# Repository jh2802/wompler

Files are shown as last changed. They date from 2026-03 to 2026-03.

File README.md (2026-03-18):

# wompler
Wompler - 8 Voice Digital Sampler with MIDI Input for Eurorack

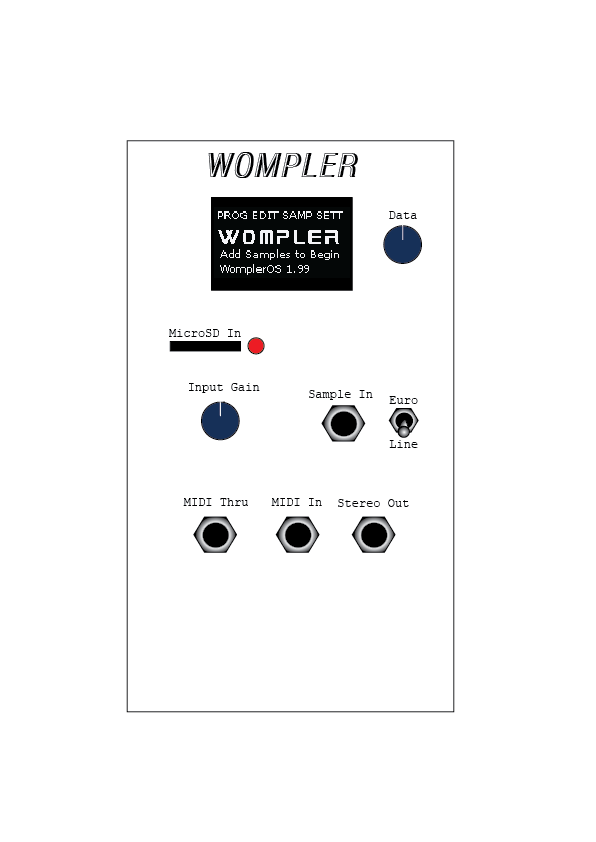
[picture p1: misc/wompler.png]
Wompler Image


ESP32 Based hardware, you can DIY this project for under $100, heck, you could make 5 for around that price.

Simplified software build instructions:
<br>
Tested with Arduino 1.8.19 using the espressif Arduino core for the ESP32 board version 2.0.11 
<br>
Place the folder "sources/streams_generator_i2sexperiment227" into your arduino sketches folder
<br>
Move the libraries from "/libraries" to your arduino libraries folder
<br>
find the line "#include "C:\Users\JJ Hardt\Documents\arduino-1.8.19\portable\sketchbook\libraries\audio-tools\src\AudioTools\MusicalNotes.h" and replace it with your correct install
<br>
Wompler manual:
<br>
https://docs.google.com/document/d/1GjeHvt_AO2QE2bgJas3L68PRGj3EGleQ7ScGcbaWzwo/edit?usp=sharing

Gerber files, PNP, and 3d printed panel found in "/hardware" folder as well as EasyEDA files

<a href="https://www.youtube.com/shorts/Yl5tXINzOkQ">Youtube audio demo:</a><br>
This demo shows an older version of wthe Wompler off

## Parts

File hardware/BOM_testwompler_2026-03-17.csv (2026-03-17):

ID | Name | Designator | Footprint | Quantity | Manufacturer Part | Manufacturer | Supplier | Supplier Part | Price
1 | 1uF | C1 | CAP-SMD_BD4.0-L4.3-W4.3-FD-LS5.1 | 1 | EEE1HA010NR | PANASONIC(松下) | LCSC | C401606 | 0.19
2 | 100nF | C2,C3,C4,C5,C6,C7,C16,C18,C21,C23,C25,C28,C29,C30,C31,C34,C35 | C0805 | 17 | CC0805KRX7R9BB104 | YAGEO(国巨) | LCSC | C49678 | 0.005
3 | 22uF | C8,C19,C22,C26,C32,C33 | C0805 | 6 | CL21A226MAQNNNE | SAMSUNG(三星) | LCSC | C45783 | 0.031
4 | 2.2nF | C10,C11 | C0805 | 2 | CL21C222JBFNNNE | SAMSUNG(三星) | LCSC | C28260 | 0.033
5 | 2.2uF | C12,C14 | C0402 | 2 | CL05A225MQ5NSNC | SAMSUNG(三星) | LCSC | C12530 | 0.003
6 | 10uF | C15,C17,C20,C24,C27 | C1206 | 5 | CL31A106KBHNNNE | SAMSUNG(三星) | LCSC | C13585 | 0.062
7 | 1N4148WS T4 | D1 | SOD-323_L1.8-W1.3-LS2.5-RD | 1 | 1N4148WS | CJ(江苏长电/长晶) | LCSC | C2128 | 0.009
8 | LED | D2 | LED-TH_LED-DP2-2LED-AMCC | 1 | 5600 | VccLite | Digi-Key | L20325-ND
9 | 100k | GAIN | BOURNS PTV09 GS | 1 | PTT111-3217A-B503 | Bourns | Mouser | 652-PTT111-3217A-B503
10 | AUDIO INPUT | J1 | WQP_PJ301M-12 | 1
11 | PROGRAM | J2 | HEADER MALE 2X3 P2.54 | 1 | PH2-06-UA | Adam Tech | Digi-Key | 2057-PH2-06-UA-ND
12 | AUDIO_OUT | J3 | PJ301_THONKICONN4 - FRONT PANEL W/ 6.05MM HOLE V2 | 1 |  | THONK | Thonk | PJ366ST
13 | PJ366ST | J4 | PJ301_THONKICONN4 - FRONT PANEL W/ 6.05MM HOLE V2 | 1 |  | THONK | Thonk | PJ366ST
14 | THRU | J5 | PJ301_THONKICONN4 - FRONT PANEL W/ 6.05MM HOLE V2 | 1 |  | THONK | Thonk | PJ366ST
15 | POWER | P1 | HDR-TH_16P-P2.54-V-M-R2-C8-S2.54 | 1 | 2.54-2*8P针 | BOOMELE(博穆精密) | LCSC | C68234 | 0.101
16 | 1kΩ | R1,R4,R11 | R0805 | 3 | 0805W8F1001T5E | UNI-ROYAL(厚声) | LCSC | C17513 | 0.003
17 | 10kΩ | R2,R18,R21,R22 | R0805 | 4 | 0805W8F1002T5E | UNI-ROYAL(厚声) | LCSC | C17414 | 0.003
18 | 2.2kΩ | R3 | R0805 | 1 | 0805W8F2201T5E | UNI-ROYAL(厚声) | LCSC | C17520 | 0.002
19 | 100R | R5,R6 | R0805 | 2 | 0805W8F1000T5E | UNI-ROYAL(厚声) | LCSC | C17408 | 0.002
20 | 47Ω | R7,R8,R9,R10 | R0805 | 4 | 0805W8F470JT5E | UNI-ROYAL(厚声) | LCSC | C17714 | 0.002
21 | 0Ω | R12,R35,R36 | R1206 | 3 | 1206W4F0000T5E | UNI-ROYAL(厚声) | LCSC | C17888 | 0.004
22 | 22Ω | R13,R14,R16 | R0805 | 3 | 0805W8F220JT5E | UNI-ROYAL(厚声) | LCSC | C17561 | 0.002
23 | 470Ω | R15,R17,R32 | R0805 | 3 | 0805W8F4700T5E | UNI-ROYAL(厚声) | LCSC | C17710 | 0.002
24 | 50Ω | R19,R27 | R0805 | 2 | ARG05FTC0500 | Viking(光颉) | LCSC | C2828866 | 0.009
25 | 270Ω | R20 | R0805 | 1 | 0805W8F2700T5E | UNI-ROYAL(厚声) | LCSC | C17590 | 0.003
26 | 100Ω | R23,R26 | R0603 | 2 | 0603WAF1000T5E | UNI-ROYAL(厚声) | LCSC | C22775 | 0.001
27 | 4.7kΩ | R24,R25,R28,R29,R31 | R0805 | 5 | 0805W8F4701T5E | UNI-ROYAL(厚声) | LCSC | C17673 | 0.002
28 | 220Ω | R30 | R0402 | 1 | 0402WGF2200TCE | UNI-ROYAL(厚声) | LCSC | C25091 | 0.001
29 | 10Ω | R33 | R1206 | 1 | 1206W4F100JT5E | UNI-ROYAL(厚声) | LCSC | C17903 | 0.004
30 | 33Ω | R34 | R0603 | 1 | 0603WAJ0330T5E | UNI-ROYAL(厚声) | LCSC | C25232 | 0.001
31 | 0Ω | R40,R41 | R2010 | 2 | WR20X000PTL | Walsin(华新科) | LCSC | C168598 | 0.012
32 | SW-T3-1A-A-A3-S1 | SW1 | SW-T3-1A-A-A3-S1 | 1 | SW-T3-1A-A-A3-S1 | Adam Tech | Digi-Key | 2057-SW-T3-1A-A-A3-S1-ND
33 | EC11E156T402 | SW2 | SW-TH_EC11E156T402 | 1 | EC11E156T402 | ALPSALPINE(阿尔卑斯阿尔派) | LCSC | C2687292 | 2.22
34 | TL072CDT | U1 | SOIC-8_L5.0-W4.0-P1.27-LS6.0-BL | 1 | TL072CDT | ST(意法半导体) | LCSC | C6961 | 0.186
35 | PCM1808PWR | U2 | TSSOP-14_L5.0-W4.4-P0.65-LS6.4-BL | 1 | PCM1808PWR | TI(德州仪器) | LCSC | C55513 | 0.645
36 | ESP32-WROOM-32E-H4 | U3 | WIFI-SMD_ESP32-WROOM-32E | 1 | ESP32-WROOM-32E-H4 | ESPRESSIF(乐鑫) | LCSC | C3013935 | 4.031
37 | PCM5102APWR | U4 | TSSOP-20_L6.5-W4.4-P0.65-LS6.4-BL | 1 | PCM5102APWR | TI(德州仪器) | LCSC | C107671 | 1.43
38 | AMS1117-3.3 | U6,U7,U8,U12 | SOT-223-3_L6.5-W3.4-P2.30-LS7.0-BR | 4 | AMS1117-3.3 | AMS | LCSC | C6186 | 0.226
39 | SD CARD READER PJS008U-3000-0 | U10 | PJS008U-3000-0 | 1 | SF72S006VBAR2500 |  | Digi-Key | 670-2799-1-ND
40 | DISPLAY | U11 | 04X1-HEADER-MALE | 1 |  |  |  | undefined
41 | 6N138 | U13 | 6N138 | 1 | 6N138 | Isocom Components | LCSC | C255743 | 0.378
42 | 74LVC1G07GV,125 | U14 | SOT-753_L3.1-W1.7-P0.95-LS3.0-BR | 1 | 74LVC1G07GV,125 | Nexperia(安世) | LCSC | C12511 | 0.261
43 | TL074CDR | U9 | SOIC-14_L8.7-W3.9-P1.27-LS6.0-BL | 1 | TL074CDR | TI(德州仪器) | LCSC | C12594 | 0.199

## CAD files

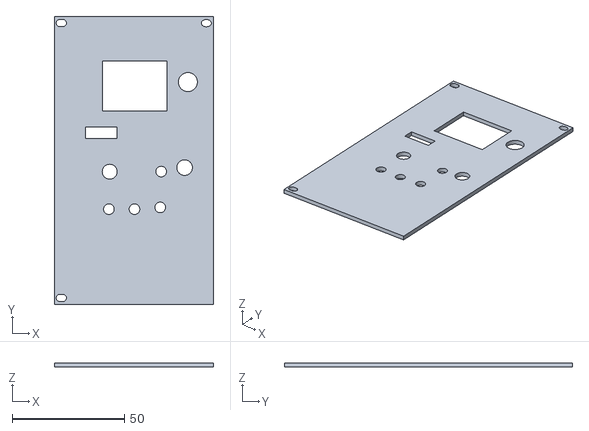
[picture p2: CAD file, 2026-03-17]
hardware/womplerrev2.stl
70.8 x 128.4 x 2.00

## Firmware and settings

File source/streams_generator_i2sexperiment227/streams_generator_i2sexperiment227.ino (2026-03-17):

/**
 * @file streams-generator-i2s.ino
 * @author Phil Schatzmann
 * @brief see https://github.com/pschatzmann/arduino-audio-tools/blob/main/examples/examples-stream/streams-generator-i2s/README.md 
 * @copyright GPLv3
 */

#include "AiEsp32RotaryEncoder.h"
#include <stack>
#include "FS.h"
#include "SD.h"
#include "SPI.h"
#include <Update.h>


//FOR WOMPLER XM TESTS
#define RX2 14
//end wompler xm test

bool preview=true;
#define SMPL 1936552044
const int16_t pb_power [24]  = {-48,-46,-44,-42,-39,-36,-32,-28,-24,-19,-13,-7,8,17,27,38,50,65,80,98,118,140,165,194};
// 'wompler1', 123x22px
const uint8_t oscmode_to_partialmode[6]={0,1,1,2,3,4};
const unsigned char epd_bitmap_wompler1 []  = {
	0x00, 0x00, 0x00, 0x00, 0x00, 0x00, 0x00, 0x00, 0x00, 0x00, 0x00, 0x00, 0x00, 0x00, 0x00, 0x00, 
	0x00, 0x00, 0x00, 0x00, 0x00, 0x00, 0x00, 0x00, 0x00, 0x00, 0x00, 0x00, 0x00, 0x00, 0x00, 0x00, 
	0x00, 0x00, 0x00, 0x00, 0x00, 0x00, 0x00, 0x00, 0x00, 0x00, 0x00, 0x00, 0x00, 0x00, 0x00, 0x00, 
	0x00, 0x00, 0x00, 0x00, 0x00, 0x00, 0x00, 0x00, 0x00, 0x00, 0x00, 0x00, 0x00, 0x00, 0x00, 0x00, 
	0x0c, 0x00, 0x60, 0x7f, 0xf0, 0x20, 0x01, 0x03, 0xff, 0x83, 0x80, 0x07, 0xfe, 0x0f, 0xfe, 0x00, 
	0x0c, 0x00, 0x60, 0x7f, 0xf0, 0x30, 0x03, 0x03, 0xff, 0x83, 0x80, 0x07, 0xfe, 0x0f, 0xfe, 0x00, 
	0x0e, 0x00, 0x60, 0xe0, 0x38, 0x38, 0x07, 0x00, 0x01, 0x83, 0x80, 0x00, 0x00, 0x00, 0x06, 0x00, 
	0x0e, 0x10, 0xe0, 0xe0, 0x38, 0x3c, 0x0f, 0x00, 0x01, 0x83, 0x80, 0x00, 0x00, 0x00, 0x06, 0x00, 
	0x0e, 0x38, 0xe0, 0xe0, 0x38, 0x3e, 0x1f, 0x00, 0x01, 0x83, 0x80, 0x00, 0x00, 0x00, 0x06, 0x00, 
	0x0e, 0x7c, 0xe0, 0xe0, 0x38, 0x3f, 0x1f, 0x80, 0x01, 0x83, 0x80, 0x00, 0x00, 0x00, 0x06, 0x00, 
	0x0e, 0xfe, 0xe0, 0xe0, 0x38, 0x3b, 0xbb, 0x80, 0x03, 0x83, 0x80, 0x07, 0xfc, 0x0f, 0xfe, 0x00, 
	0x0f, 0xef, 0xe0, 0xe0, 0x38, 0x3b, 0xf3, 0x83, 0xff, 0x83, 0x80, 0x07, 0xfc, 0x0f, 0xfe, 0x00, 
	0x0f, 0xc7, 0xe0, 0xe0, 0x38, 0x39, 0xe3, 0x83, 0xff, 0x03, 0x80, 0x07, 0x00, 0x0e, 0x70, 0x00, 
	0x0f, 0x83, 0xe0, 0xe0, 0x38, 0x30, 0xc3, 0x83, 0x80, 0x03, 0x80, 0x07, 0x00, 0x0e, 0x30, 0x00, 
	0x0f, 0x01, 0xc0, 0xe0, 0x38, 0x30, 0x03, 0x83, 0x80, 0x03, 0x80, 0x07, 0x00, 0x0e, 0x38, 0x00, 
	0x06, 0x00, 0xc0, 0xf0, 0x78, 0x70, 0x03, 0x83, 0x80, 0x03, 0x80, 0x07, 0x00, 0x0e, 0x1c, 0x00, 
	0x04, 0x00, 0x40, 0x7f, 0xf0, 0x70, 0x03, 0x83, 0x80, 0x03, 0xff, 0x87, 0xfe, 0x0e, 0x1c, 0x00, 
	0x00, 0x00, 0x00, 0x3f, 0xe0, 0x70, 0x03, 0x83, 0x80, 0x03, 0xff, 0x87, 0xfe, 0x0e, 0x0e, 0x00, 
	0x00, 0x00, 0x00, 0x00, 0x00, 0x00, 0x00, 0x00, 0x00, 0x00, 0x00, 0x00, 0x00, 0x00, 0x00, 0x00, 
	0x00, 0x00, 0x00, 0x00, 0x00, 0x00, 0x00, 0x00, 0x00, 0x00, 0x00, 0x00, 0x00, 0x00, 0x00, 0x00, 
	0x00, 0x00, 0x00, 0x00, 0x00, 0x00, 0x00, 0x00, 0x00, 0x00, 0x00, 0x00, 0x00, 0x00, 0x00, 0x00, 
	0x00, 0x00, 0x00, 0x00, 0x00, 0x00, 0x00, 0x00, 0x00, 0x00, 0x00, 0x00, 0x00, 0x00, 0x00, 0x00
};
// 'wompler2', 123x22px
const unsigned char epd_bitmap_wompler2 []  = {
	0x00, 0x00, 0x00, 0x00, 0x00, 0x00, 0x00, 0x00, 0x00, 0x00, 0x00, 0x00, 0x00, 0x00, 0x00, 0x00, 
	0x00, 0x00, 0x00, 0x00, 0x00, 0x00, 0x00, 0x00, 0x00, 0x00, 0x00, 0x00, 0x00, 0x00, 0x00, 0x00, 
	0x3f, 0x01, 0xf9, 0xff, 0xfc, 0xf8, 0x07, 0xcf, 0xff, 0xef, 0xe0, 0x1f, 0xff, 0xbf, 0xff, 0x80, 
	0x21, 0x01, 0x09, 0x00, 0x04, 0x8c, 0x0c, 0x48, 0x00, 0x28, 0x20, 0x10, 0x00, 0xa0, 0x00, 0x80, 
	0x2d, 0x81, 0x6b, 0x7f, 0xf6, 0xa6, 0x19, 0x4b, 0xff, 0xab, 0xa0, 0x17, 0xfe, 0xaf, 0xfe, 0x80, 
	0x2c, 0xff, 0x6a, 0x7f, 0xf2, 0xb3, 0x33, 0x4b, 0xff, 0xab, 0xa0, 0x17, 0xfe, 0xaf, 0xfe, 0x80, 
	0x2e, 0xc6, 0x6a, 0xe0, 0x3a, 0xb9, 0xe7, 0x48, 0x01, 0xab, 0xa0, 0x10, 0x00, 0xa0, 0x06, 0x80, 
	0x2e, 0x92, 0xea, 0xef, 0xba, 0xbc, 0xcf, 0x6f, 0xfd, 0xab, 0xa0, 0x1f, 0xff, 0xbf, 0xf6, 0x80, 
	0x2e, 0x38, 0xea, 0xe8, 0xba, 0xbe, 0x5f, 0x20, 0x0d, 0xab, 0xa0, 0x1f, 0xff, 0x3f, 0xf6, 0x80, 
	0x2e, 0x7c, 0xea, 0xea, 0xba, 0xbf, 0x1f, 0xaf, 0xf9, 0xab, 0xa0, 0x10, 0x01, 0x20, 0x06, 0x80, 
	0x2e, 0xfe, 0xea, 0xea, 0xba, 0xbb, 0xbb, 0xa8, 0x03, 0xab, 0xa0, 0x17, 0xfd, 0x2f, 0xfe, 0x80, 
	0x2f, 0xef, 0xea, 0xea, 0xba, 0xbb, 0xf3, 0xab, 0xff, 0xab, 0xa0, 0x17, 0xfd, 0x2f, 0xfe, 0x80, 
	0x2f, 0xc7, 0xea, 0xe8, 0xba, 0xb9, 0xe3, 0xab, 0xff, 0x2b, 0xa0, 0x17, 0x01, 0x2e, 0x70, 0x80, 
	0x2f, 0x93, 0xea, 0xed, 0xbb, 0xb0, 0xcb, 0xab, 0x80, 0x6b, 0xa0, 0x17, 0x7f, 0x2e, 0x33, 0x80, 
	0x2f, 0x39, 0xca, 0xe7, 0x3b, 0x36, 0x1b, 0xab, 0xbf, 0xcb, 0xbf, 0xf7, 0x7f, 0xae, 0xb9, 0x00, 
	0x26, 0x6c, 0xda, 0xf0, 0x7b, 0x77, 0xfb, 0xab, 0xa0, 0x0b, 0x80, 0x37, 0x00, 0xae, 0x9d, 0x80, 
	0x34, 0xc6, 0x52, 0x7f, 0xf3, 0x74, 0x0b, 0xab, 0xa0, 0x0b, 0xff, 0xb7, 0xfe, 0xae, 0xdc, 0x80, 
	0x11, 0x83, 0x13, 0x3f, 0xe7, 0x74, 0x0b, 0xab, 0xa0, 0x0b, 0xff, 0xb7, 0xfe, 0xae, 0xce, 0x80, 
	0x1f, 0x01, 0xf1, 0x80, 0x0d, 0x04, 0x08, 0x28, 0x20, 0x08, 0x00, 0x30, 0x00, 0xa0, 0xe0, 0x80, 
	0x00, 0x00, 0x00, 0xff, 0xf9, 0xfc, 0x0f, 0xef, 0xe0, 0x0f, 0xff, 0xff, 0xff, 0xbf, 0xbf, 0x80, 
	0x00, 0x00, 0x00, 0x00, 0x00, 0x00, 0x00, 0x00, 0x00, 0x00, 0x00, 0x00, 0x00, 0x00, 0x00, 0x00, 
	0x00, 0x00, 0x00, 0x00, 0x00, 0x00, 0x00, 0x00, 0x00, 0x00, 0x00, 0x00, 0x00, 0x00, 0x00, 0x00
};
// 'wompler3', 123x22px
const unsigned char epd_bitmap_wompler3 []  = {
	0xff, 0xc7, 0xff, 0xff, 0xff, 0xfe, 0x1f, 0xff, 0xff, 0xff, 0xf8, 0x7f, 0xff, 0xff, 0xff, 0xe0, 
	0x80, 0x44, 0x00, 0x00, 0x00, 0x03, 0x30, 0x00, 0x00, 0x00, 0x08, 0x40, 0x00, 0x00, 0x00, 0x20, 
	0xbf, 0x65, 0xf9, 0xff, 0xfc, 0xf9, 0xe7, 0xcf, 0xff, 0xef, 0xe8, 0x5f, 0xff, 0xbf, 0xff, 0xa0, 
	0xa1, 0x3d, 0x09, 0x00, 0x04, 0x8c, 0xcc, 0x48, 0x00, 0x28, 0x28, 0x50, 0x00, 0xa0, 0x00, 0xa0, 
	0xad, 0x81, 0x6b, 0x7f, 0xf6, 0xa6, 0x19, 0x4b, 0xff, 0xab, 0xa8, 0x57, 0xfe, 0xaf, 0xfe, 0xa0, 
	0xac, 0xff, 0x6a, 0x7f, 0xf2, 0xb3, 0x33, 0x4b, 0xff, 0xab, 0xa8, 0x57, 0xfe, 0xaf, 0xfe, 0xa0, 
	0xae, 0xc6, 0x6a, 0xe0, 0x3a, 0xb9, 0xe7, 0x48, 0x01, 0xab, 0xa8, 0x50, 0x00, 0xa0, 0x06, 0xa0, 
	0xae, 0x92, 0xea, 0xef, 0xba, 0xbc, 0xcf, 0x6f, 0xfd, 0xab, 0xa8, 0x5f, 0xff, 0xbf, 0xf6, 0xa0, 
	0xae, 0x38, 0xea, 0xe8, 0xba, 0xbe, 0x5f, 0x20, 0x0d, 0xab, 0xa8, 0x5f, 0xff, 0x3f, 0xf6, 0xa0, 
	0xae, 0x7c, 0xea, 0xea, 0xba, 0xbf, 0x1f, 0xaf, 0xf9, 0xab, 0xa8, 0x50, 0x01, 0x20, 0x06, 0xa0, 
	0xae, 0xfe, 0xea, 0xea, 0xba, 0xbb, 0xbb, 0xa8, 0x03, 0xab, 0xa8, 0x57, 0xfd, 0x2f, 0xfe, 0xa0, 
	0xaf, 0xef, 0xea, 0xea, 0xba, 0xbb, 0xf3, 0xab, 0xff, 0xab, 0xa8, 0x57, 0xfd, 0x2f, 0xfe, 0xa0, 
	0xaf, 0xc7, 0xea, 0xe8, 0xba, 0xb9, 0xe3, 0xab, 0xff, 0x2b, 0xaf, 0xd7, 0x01, 0x2e, 0x70, 0xa0, 
	0xaf, 0x93, 0xea, 0xed, 0xbb, 0xb0, 0xcb, 0xab, 0x80, 0x6b, 0xa0, 0x17, 0x7f, 0x2e, 0x33, 0xa0, 
	0xaf, 0x39, 0xca, 0xe7, 0x3b, 0x36, 0x1b, 0xab, 0xbf, 0xcb, 0xbf, 0xf7, 0x7f, 0xae, 0xb9, 0x20, 
	0xa6, 0x6c, 0xda, 0xf0, 0x7b, 0x77, 0xfb, 0xab, 0xa0, 0x0b, 0x80, 0x37, 0x00, 0xae, 0x9d, 0xa0, 
	0xb4, 0xc6, 0x52, 0x7f, 0xf3, 0x74, 0x0b, 0xab, 0xaf, 0xeb, 0xff, 0xb7, 0xfe, 0xae, 0xdc, 0xa0, 
	0x91, 0x93, 0x13, 0x3f, 0xe7, 0x75, 0xeb, 0xab, 0xa8, 0x2b, 0xff, 0xb7, 0xfe, 0xae, 0xce, 0xa0, 
	0xdf, 0x39, 0xf1, 0x80, 0x0d, 0x05, 0x28, 0x28, 0x28, 0x28, 0x00, 0x30, 0x00, 0xa0, 0xe0, 0xa0, 
	0x40, 0x6c, 0x04, 0xff, 0xf9, 0xfd, 0x2f, 0xef, 0xe8, 0x2f, 0xff, 0xff, 0xff, 0xbf, 0xbf, 0xa0, 
	0x7f, 0xc7, 0xfe, 0x00, 0x00, 0x01, 0x20, 0x00, 0x08, 0x20, 0x00, 0x00, 0x00, 0x00, 0x00, 0x20, 
	0x00, 0x00, 0x03, 0xff, 0xff, 0xff, 0x3f, 0xff, 0xf8, 0x3f, 0xff, 0xff, 0xff, 0xff, 0xff, 0xe0
};

// Array of all bitmaps for convenience. (Total bytes used to store images in  = 1104)





#define VOICE_QT 8
//#define LFO_QT 2 * VOICE QT
#define RIFF 1380533830
#define WAVE 1463899717
#define FACT 1717658484
#define DATA_ID 1684108385
const char *my_file;
#define FMTT 1718449184

#define FIRMWARE_VERSION "Build 31026"
//int long_press;
uint8_t voice2pitch[VOICE_QT];
bool enable_click=true;
int update_prog=0;
uint8_t pb_range=0;
bool dual_init=false;
String filename;
uint8_t edit_dest;
bool is_replace=false;
#include "do1.h"
bool sustain=false;
uint8_t sample_length=172;
uint8_t sample_threshold=0;
uint8_t sample_pos=0;
int samp_level_average_cache=0;
int8_t samp_level_average=0;
bool sd_init=false;
float boost_factor=1.0;
uint8_t dir_pos=0;
uint8_t edit_wavesample_2=0;
int edit_wavesample_buffer=0;
bool keystate[128];
const char *test_dir = "/";
const char *prev_dir = "/";
const char *file_save_path ="/test";
const char *test_dir_root = "/";
char sample_name[9]="USERSAMP";
int16_t next_dir_pos=0;
int16_t prev_dir_pos=0;
uint8_t fm_type=0;
File root;
File dir_file;
File dir_file_cache;
File prev_dir_file[6];
int8_t file_layer=0;
extern bool getKeystate(byte key){
    return keystate[key];
}

int8_t old_sample_pos;


#define ROTARY_ENCODER_A_PIN 25
#define ROTARY_ENCODER_B_PIN 27
#define ROTARY_ENCODER_BUTTON_PIN 4
#define ROTARY_ENCODER_STEPS 4
#define ROTARY_ENCODER_VCC_PIN -1 
#define SAMP_LEN 512

#define STEAL_FADE_TIME 4096
#define LOWPASS 0
#define HIGHPASS 1

#define WSB_HEADER 826430295
#define WSB2_HEADER 843207511
#define WSB3_HEADER 859984727
int8_t wavesample_combine=0;
bool sample_ready=false;
bool ld_default=false;
bool oscy=false;
char key2voice[128];
int8_t zoom=0;
bool queue_test=false;
uint8_t midi_channel=1;
uint8_t gp_reg8b=0;
bool nprog=0;
uint8_t gp_reg8a=0; //used for splashscreen animation and rectify mode
int8_t user_wavesamples = 0;
void writeFile(fs::FS &fs, const char * path, const char * message){
    Serial.printf("Writing file: %s\n", path);

    File file = fs.open(path, FILE_WRITE);
    if(!file){
        Serial.println("Failed to open file for writing");
        return;
    }
    if(file.print(message)){
        Serial.println("File written");
    } else {
        Serial.println("Write failed");
    }
    file.close();
}


void appendFile(fs::FS &fs, const char * path, const char * message){
    Serial.printf("Appending to file: %s\n", path);

    File file = fs.open(path, FILE_APPEND);
    if(!file){
        Serial.println("Failed to open file for appending");
        return;
    }
    if(file.print(message)){
        Serial.println("Message appended");
    } else {
        Serial.println("Append failed");
    }
    file.close();
}
SPIClass sd_spi(HSPI);

#define SD_CS 5
#define SD_MOSI 23
#define SD_MISO 19
#define SD_SCLK 18


#define FM_SAMPLE 0
#define FM_BANK 1
#define FM_DIRWAV 2
#define FM_DIRBNK 3
//char voice2key[max_voices]={255,255,255,255,255,255}; 
//byte queuePitch[max_voices]={0,0,0,0,0,0};
//byte queueVelo[max_voices]={0,0,0,0,0,0};
char voice2key[VOICE_QT]={255,255,255,255,255,255,255,255}; 
byte queuePitch[VOICE_QT]={0,0,0,0,0,0};
byte queueVelo[VOICE_QT]={0,0,0,0,0,0};
#define WAVESAMPLE_AMOUNT 100
#define PROGRAM_AMOUNT 64
#define VOICE_HF VOICE_QT>>1
bool voices_init=false;
byte last_velo=0;
#define DEFAULT 0
#define PER_WAVESAMPLE 1
#define POLY2 2
byte poly_mode=DEFAULT;
#define ROUND_ROBIN 2
#include <MIDI.h>
#include "logtable.h"
//#include "sqlw.h"

AiEsp32RotaryEncoder rotaryEncoder = AiEsp32RotaryEncoder(ROTARY_ENCODER_A_PIN, ROTARY_ENCODER_B_PIN, ROTARY_ENCODER_BUTTON_PIN, ROTARY_ENCODER_VCC_PIN, ROTARY_ENCODER_STEPS);

extern void setQueuedNote(byte voice,byte pitch,byte velo) {
queuePitch[voice]=pitch;
queueVelo[voice]=velo;

}



#include <Wire.h>
#include <Adafruit_GFX.h>
#include <Adafruit_SSD1306.h>


#define LOGO16_GLCD_HEIGHT 16
#define LOGO16_GLCD_WIDTH  16
#define SCREEN_WIDTH 128 // OLED display width, in pixels
#define SCREEN_HEIGHT 64 // OLED display height, in pixels
#define OLED_RESET     -1 // Reset pin # (or -1 if sharing Arduino reset pin)
#define SCREEN_ADDRESS 0x3C ///< See datasheet for Address; 0x3D for 128x64, 0x3C for 128x32
Adafruit_SSD1306 display(SCREEN_WIDTH, SCREEN_HEIGHT, &Wire, OLED_RESET);
#include "AudioTools.h"
#include "C:\Users\JJ Hardt\Documents\arduino-1.8.19\portable\sketchbook\libraries\audio-tools\src\AudioTools\MusicalNotes.h"
int8_t samp_level_buffer[128]={};
bool sampling_level=false;
//ChannelConverter<int32_t> converter(16,32);
AudioInfo from(30000,2,24);
AudioInfo to(30000,2,16);
MemoryOutput samp_mem_out{(uint8_t*)samp_memory,88064};
MemoryOutput samp_level{(uint8_t*)samp_level_buffer,128};
ConverterFillLeftAndRight<int16_t> sampfix(LeftIsEmpty,2);
volatile int16_t lfo[VOICE_QT];
volatile uint8_t random_counter[VOICE_QT];
volatile int16_t saw[VOICE_QT];
volatile int16_t tri;
//int totalInterruptCounter;

hw_timer_t * timer = NULL;
portMUX_TYPE timerMux = portMUX_INITIALIZER_UNLOCKED;
MIDI_CREATE_INSTANCE(HardwareSerial, Serial2, DIN_MIDI);
const uint16_t sample_rate=30000;
const uint8_t channels = 2;
char mode=0;    
int men[VOICE_QT];

char voice2ws[VOICE_QT];             
AudioInfo sampy(sample_rate,1,8);
byte program=0;

//AUDIO PROCESS FILTER CONSTANTS
#define FILTER_D_LP 0
#define FILTER_D_HP 1
#define FILTER_D_BP 2
#define FILTER_D_BR 3
#define FILTER_D_PKG 4

//DISPLAY CONTEXT CONSTANTS

//MAIN MENU
#define PROG 0
#define SAMPLE 2
#define EDIT 1
#define SETTINGS 3

// EDIT MENU
#define EDIT_SAMP 4
#define AMP_MENU 5
#define MOD_MENU 6
#define MORE 7

#define LOOP_MENU 8
#define FILTER 9
#define KEYSET 10
#define MORE_SAMPEDIT 11
//AMP EG MENU
#define AMP_EG_ATK 12
#define AMP_EG_DEC 13
#define AMP_EG_SUS 14
#define AMP_EG_REL 15

//keyset menu
#define KEYSET_TOPKEY 216
#define KEYSET_CTUNE 217
#define KEYSET_KEYT 218
#define KEYSET_FTUNE 219
#define KEYSET_PORTATIME 220
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
void loop() {
  //Serial.println(is_replace);
  if (sampling==true){

  if (samp_num<sample_length ){
  // sample_copy.copy();
   sample_copy.copy();
   samp_num++;
   Serial.println(samp_num);
   } 

   if (samp_num==sample_length){
      displaycontext=SAMPLE_EDITOR;
      sampling=false;
      uint8_t user_wavesamples_cache=user_wavesamples;
      if (is_replace==true){user_wavesamples=edit_wavesample;}
       wavesample_start[user_wavesamples]=(sample_pos*512);
      wavesample_loopst[user_wavesamples]=wavesample_start[user_wavesamples];
      wavesample_end[user_wavesamples]=wavesample_start[user_wavesamples]+(sample_length*512)-1;
       wavesample_loopen[user_wavesamples]=wavesample_end[user_wavesamples];
       edit_wavesample=user_wavesamples;
       if (is_replace==false){ user_wavesamples++;} else{
user_wavesamples=user_wavesamples_cache;
       }
       if (nprog==true){
         program=user_programs;
         program++;
         program_init_ws[program]=edit_wavesample;
          user_programs++;
          prev_osc_mode=osc_mode;
          osc_mode=0;
  poly_mode=0;
       }
       menuoffset=ZOOM-4;
       hovermode=true;
       hovercontext=ZOOM;
       rotaryEncoder.setEncoderValue(4);
       rotaryEncoder.setBoundaries(0,7, true); 
      refreshDisplay();
     
      sample_pos+=sample_length;
     
      
      copier.begin(out,voice_mixer);
   }
   
   /*else {
     if (ld_default==false){
loadBank(SD, "/default.wsb");
refreshDisplay();
  copier.begin(out,voice_mixer);
ld_default=true;

     }
     sampling=false;
   
   }*/
  
  } else {
  
  if (sampling_level==false){
    copier.copy();}
    
if (sampling_level==true){
  //copier1.copy();
level_copy.copy();

samp_level_average=samp_level_average_cache;
samp_level_average_cache=0;
for(int i=0;i<128;i++){

samp_level_average_cache+=abs(samp_level_buffer[i]);

}
samp_level_average_cache=samp_level_average_cache/128;
samp_level_average=((samp_level_average_cache + samp_level_average)/2);
 samp_level.reset();
  if (sample_ready==false){

  refreshDisplay();
  }

if ((sample_ready==true) && (samp_level_average>=sample_threshold)){
   // copier.begin(out,converter);
    sampling=true;
  refreshDisplay();
      samp_mem_out.setPosX(((int)(sample_pos)*512));
      samp_mem_out.begin();
     
      //samp_level.begin();
      //bitcrush.begin();
      //final_samp.begin(2,1);
      sample_copy.begin();
     // level_copy.end();
     samp_num=0;
      sampling_level=false;
     sample_ready=false;
    // sampling=true;
      auto config_in = adc.defaultConfig(RX_MODE);
config_in.buffer_count=4;
  config_in.buffer_size=512;

     

}


 

}
   


//recording a sample



  /*
  Serial.println(String(esp_get_free_heap_size()));
  out.end();
 
 int sample_timer=0;

 while (sample_timer<512){
   
   if (adc.available()==512){

 size_t len = adc.readBytes(samp_buff, 512); 
  // move center to 0 and scale the values
  scaler.convert(samp_buff, len);

  int16_t *sample = (int16_t*) samp_buff; 
 
  for (int j=0; j<len/2; j++){
    int xj=j+(sample_timer*256);
    samp_memory[xj]=(*sample++);
  ;
  }
sample_timer++;
}
}
/*
 auto config = out.defaultConfig(TX_MODE);
  config.buffer_count=4;
  config.buffer_size=64;
  config.sample_rate = sample_rate; 
  config.channels = channels;
  config.port_no=1;
  config.bits_per_sample = 16;
out.begin(config);

 for (int i;i<65536;i++){
  Serial.println( samp_memory[i] ); };

   size_t len = adc.readBytes(samp_buff, 256); 
  // move center to 0 and scale the values
  scaler.convert(samp_buff, len);

  int16_t *sample = (int16_t*) samp_buff; 
  int size = len;// / 4;
  for (int j=0; j<size; j++){
    samp_memory[j+(m*4096)]=(*sample++);
  }
Wire.beginTransmission(0x55);
  Wire.write(200);
Wire.endTransmission(); 
  m++; 
//Write message to the slave

  // Clear the buffer.
 
 
  
 
 

 */

 
if (laststate==HIGH && digitalRead(13)==LOW){

onButtonClick();

}
laststate=digitalRead(13);

//splash animation frames
if ((user_wavesamples==0) && (displaycontext==EDIT)){
  gp_reg8b+=4;
if (gp_reg8b==0){gp_reg8a+=64;refreshDisplay();}//to slow it down further. 7 is the speed
}

//rotary_loop();
for (byte i=0;i<max_voices;i++){
    
    if (queueVelo[i]>0){
     // Serial.println(queuePitch[i]);
  
      if ((partials[i]->isActive()==false) || (queuePitch[i]!=voice2key[i])){
        //Serial.println("bsteal");
     handleNoteOnX(midi_channel,queuePitch[i],queueVelo[i]);
     queue_test=true;
      queuePitch[i]=0;
      queueVelo[i]=0;}
    }
    
    }



//digitalWrite(19,oscy);
  /*  bool notesHeld;
for (char i;i<127;i++){
       if (keystate[i]==true){
         notesHeld=true;
       }}

if (notesHeld==false){
for (char i;i<max_voices;i++){
if (p_amp_env[i]->isActive)
}*/
/*
if (prev_osc_mode!=osc_mode){


if (prev_osc_mode==NORMAL && osc_mode!=NORMAL){
//sample_rate=20000;
switchDualMode();
  //prev_osc_mode=osc_mode;
 prev_osc_mode= osc_mode;
 dual_init=true;
} else if (prev_osc_mode!=NORMAL && osc_mode==NORMAL) {
//sample_rate=30000;
switchNormalMode();
  //prev_osc_mode=NORMAL;
prev_osc_mode= osc_mode;
dual_init=false;
  } 


  if (prev_osc_mode!=FM_MODE && osc_mode==FM_MODE){
for (int i=0;i<max_voices;i++){
  partials[i]->setMode(2);
}

  }

   if (prev_osc_mode!=CHORUS_MODE && osc_mode==CHORUS_MODE){
for (int i=0;i<max_voices;i++){
  partials[i]->setMode(1);
}

  }

  if (prev_osc_mode!=DUAL_MODE && osc_mode==DUAL_MODE){
for (int i=0;i<max_voices;i++){
  partials[i]->setMode(1);
}

  }

} else if ((prev_osc_mode!=NORMAL) && (dual_init==false)){
  switchDualMode();
  prev_osc_mode= osc_mode;
  dual_init=true;
}
*/




//offset mod fixes
   char my_wavesample;
for (byte j=0;j<max_voices;j++){
  my_wavesample=voice2ws[j];

  if (wavesample_so_mod[my_wavesample]==LFO){ 
  
  //byte shiftornot=0;
  //if (lfo_shape[j]==1){shiftornot=1;}
  float test1;

  if ((lfo_shape[j])==0){ //saw
     test1=(((((lfo[j]+16384))) * lfo_depth[j])/4194304.0);
    } else {
        test1=(((((lfo[j]+32768))>>1) * lfo_depth[j])/4161536.0);
      }
 
  //float test1=(((((lfo[j]+32768))>>1) * lfo_depth[j])/4161536.0);
  /* classic offset mod (non-wavetable)
float test2=(wavesample_end[my_wavesample]-wavesample_loopen[my_wavesample]);
test2=test1*test2;
//Serial.println(test2);
 partials[j]->setOffset((int)test2);*/
 int looplen=wavesample_loopen[my_wavesample]-wavesample_loopst[my_wavesample];
float test2=(test1*((wavesample_end[my_wavesample]-wavesample_start[my_wavesample])-looplen))/looplen;
test2=floor(test2)*looplen;
  partials[j]->setOffset((int)test2);
  if (osc_mode!=NORMAL){
    if (osc_mode!=CHORUS_MODE){
    int8_t my_wsb=wavesample_wsb[my_wavesample];
looplen=wavesample_loopen[my_wsb]-wavesample_loopst[my_wsb];
test2=(test1*((wavesample_end[my_wsb]-wavesample_start[my_wsb])-looplen))/looplen;
test2=floor(test2)*looplen;
      dualosc[j]->setOffset((int)test2);} else { dualosc[j]->setOffset((int)test2);}
  }
  }

   if (wavesample_so_mod[my_wavesample]==MOD_ENV){ 
  
float test1=(((men[j]) * (wavesample_menv_depth[my_wavesample]+127))/4161536.0);
 int looplen=wavesample_loopen[my_wavesample]-wavesample_loopst[my_wavesample];
float test2=(test1*((wavesample_end[my_wavesample]-wavesample_start[my_wavesample])-looplen))/looplen;
test2=floor(test2)*looplen;

 /*
  float test1=(((men[j]) * (wavesample_menv_depth[my_wavesample]+127))/4161536.0);
 
 
float test2=(wavesample_end[my_wavesample]-wavesample_loopen[my_wavesample]);
 float max_os=test2/looplen;
test2=test1*test2;
//Serial.println(test2);*/
 partials[j]->setOffset((int)test2);
   if (osc_mode!=NORMAL){
    if (osc_mode!=CHORUS_MODE){
    int8_t my_wsb=wavesample_wsb[my_wavesample];
looplen=wavesample_loopen[my_wsb]-wavesample_loopst[my_wsb];
test2=(test1*((wavesample_end[my_wsb]-wavesample_start[my_wsb])-looplen))/looplen;
test2=floor(test2)*looplen;
      dualosc[j]->setOffset((int)test2);} else { dualosc[j]->setOffset((int)test2);}
  }
  }

  
   if (wavesample_so_mod[my_wavesample]==VELOCITY){ 
  
float test1=(p_velo[j]/127.00);
 int looplen=wavesample_loopen[my_wavesample]-wavesample_loopst[my_wavesample];
float test2=(test1*((wavesample_end[my_wavesample]-wavesample_start[my_wavesample])-looplen))/looplen;
test2=floor(test2)*looplen;
 if (osc_mode!=NORMAL){
    if (osc_mode!=CHORUS_MODE){
    int8_t my_wsb=wavesample_wsb[my_wavesample];
looplen=wavesample_loopen[my_wsb]-wavesample_loopst[my_wsb];
test2=(test1*((wavesample_end[my_wsb]-wavesample_start[my_wsb])-looplen))/looplen;
test2=floor(test2)*looplen;
      dualosc[j]->setOffset((int)test2);} else { dualosc[j]->setOffset((int)test2);}
  }
 /*
  float test1=(((men[j]) * (wavesample_menv_depth[my_wavesample]+127))/4161536.0);
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
